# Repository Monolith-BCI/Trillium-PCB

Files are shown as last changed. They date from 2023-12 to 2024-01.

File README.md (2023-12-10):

## Monolith

We're a group of teens working on creating a BCI PCB to start running our own experiments on noise filtering, signal processing speed, and data collection. Our board takes in electrode data from 8 electrodes, and outputs the data over SPI so that we can process it with a neural network.

## Setup

KiCad plugins that we highly suggest installing:

* [`espressif/kicad-libraries`](https://github.com/espressif/kicad-libraries): KiCad libraries for Espressif chips and modules

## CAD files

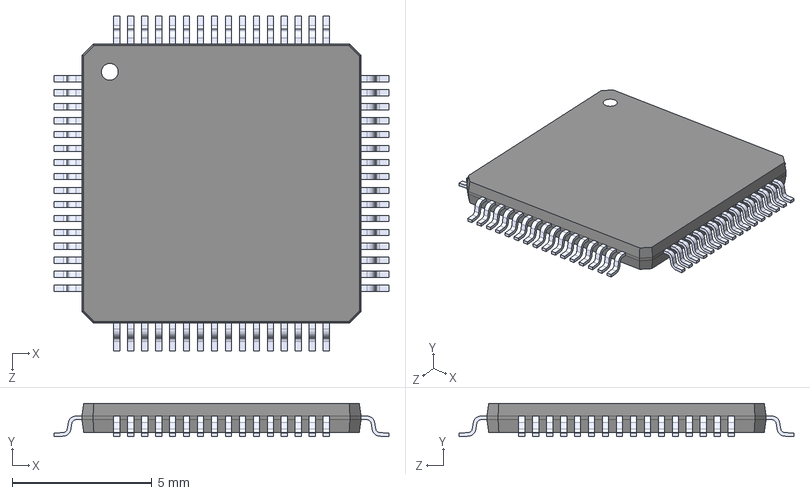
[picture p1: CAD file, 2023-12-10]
ADS1299IPAGR/ADS1299IPAGR.step
12.0 x 1.20 x 12.0 mm

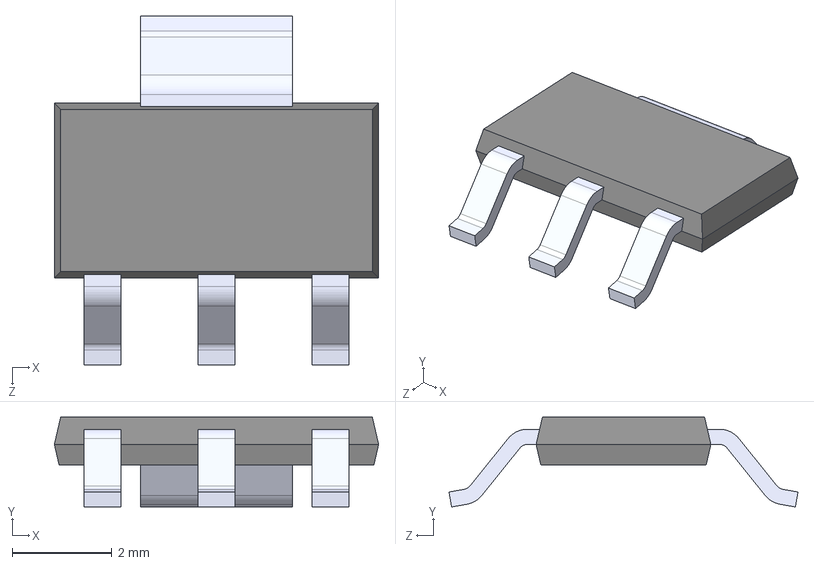
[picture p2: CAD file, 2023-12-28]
AMS1117-3.3/AMS1117-3.3.step
6.50 x 1.80 x 7.00 mm

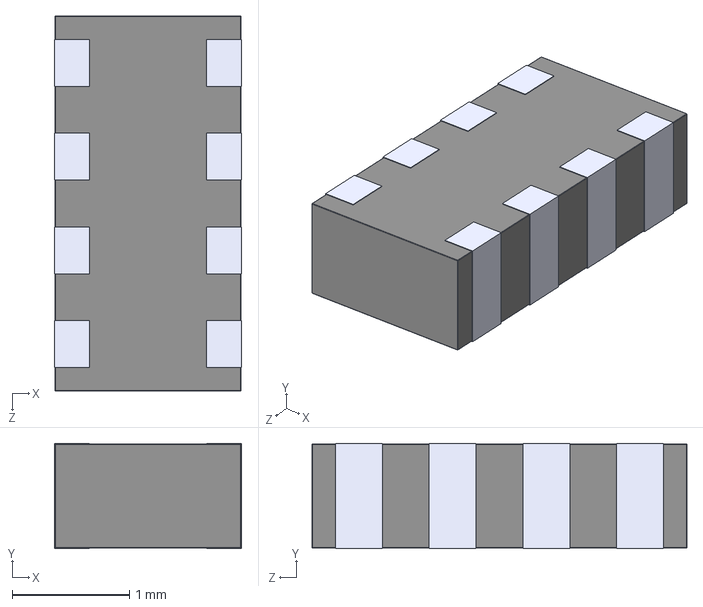
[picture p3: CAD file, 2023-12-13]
CA0612KRX7R9BB102/CA0612KRX7R9BB102.step
1.60 x 0.9 x 3.20 mm

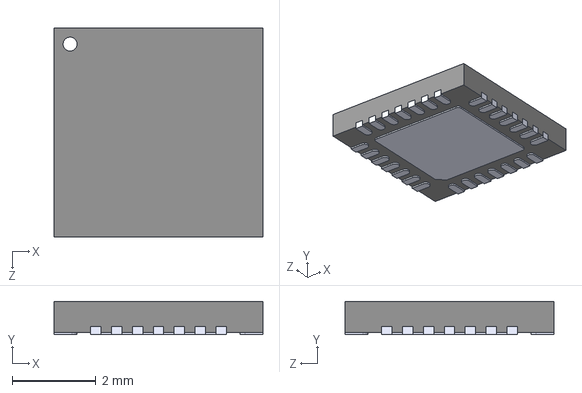
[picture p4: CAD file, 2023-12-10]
CP2102N_A02_GQFN28R/CP2102N-A02-GQFN28R.step
5.00 x 0.8 x 5.00 mm

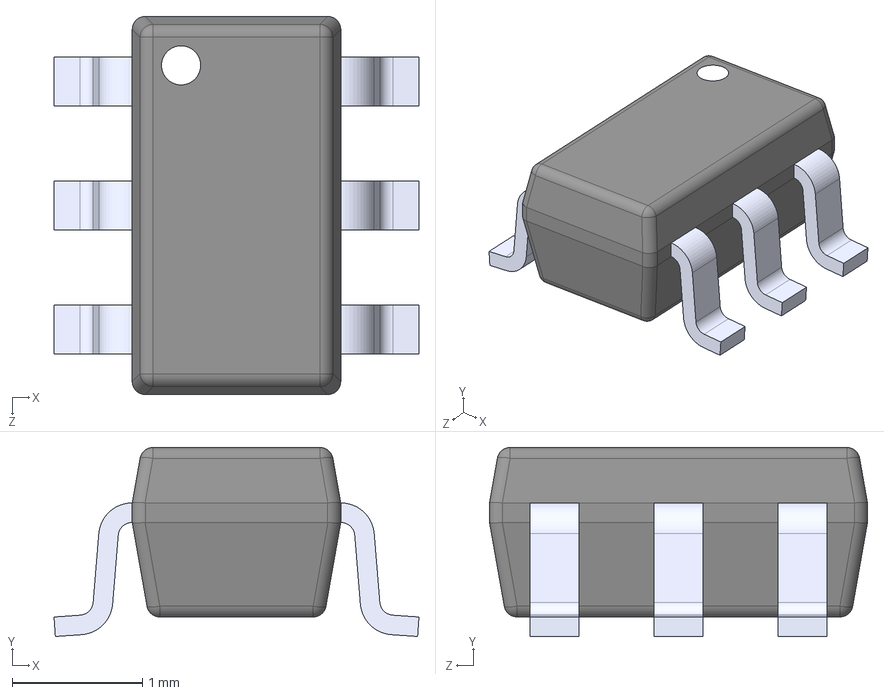
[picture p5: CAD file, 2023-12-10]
LM2664M6/LM2664M6.step
2.80 x 1.45 x 2.90 mm

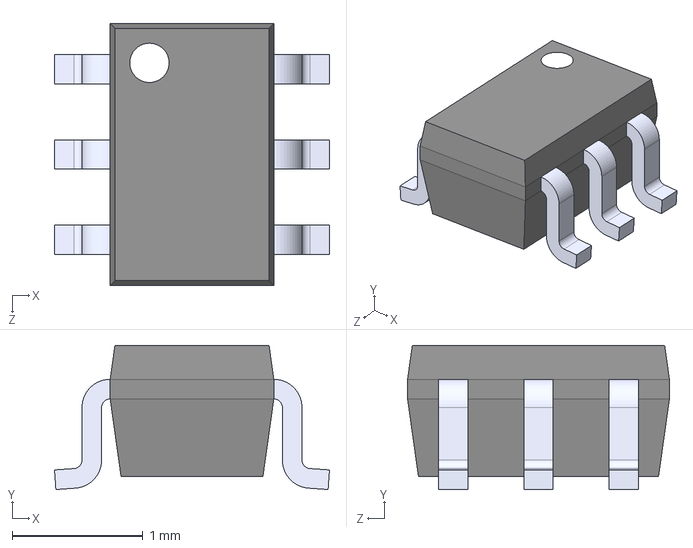
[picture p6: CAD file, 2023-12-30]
TPD4E1B06DCKR /TPD4E1B06DCKR.step
2.10 x 1.10 x 2.00 mm

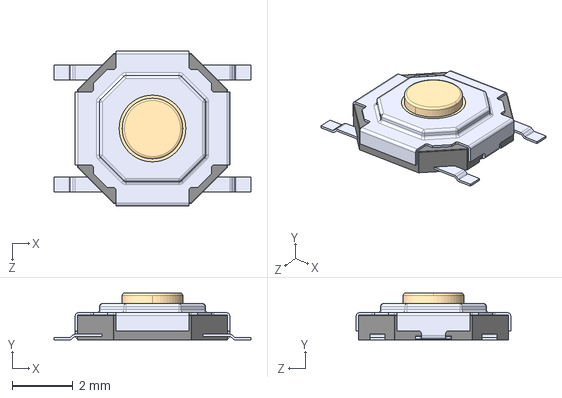
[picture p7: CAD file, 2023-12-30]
TS-1187A-B-A-B/TS-1187A-B-A-B.step
6.50 x 1.55 x 5.10 mm

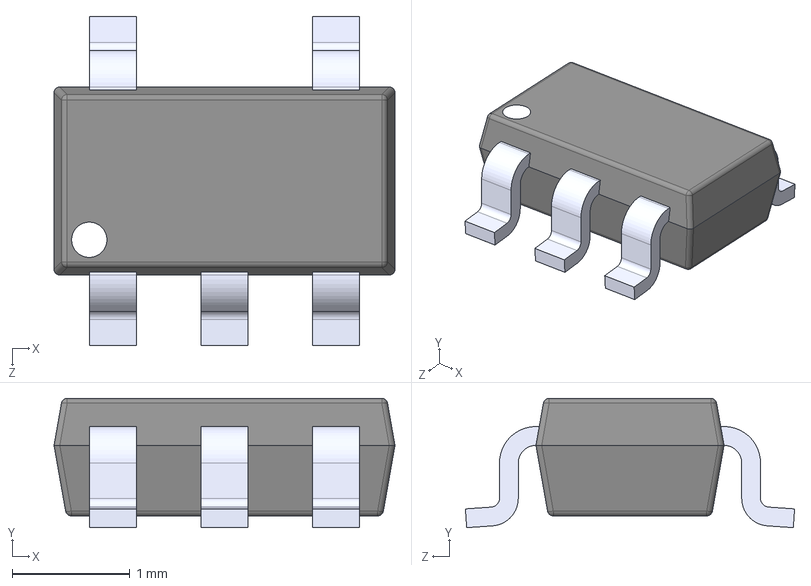
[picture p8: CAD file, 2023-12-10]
TLV70025QDDCRQ1/TLV70025QDDCRQ1.step
2.90 x 1.10 x 2.80 mm

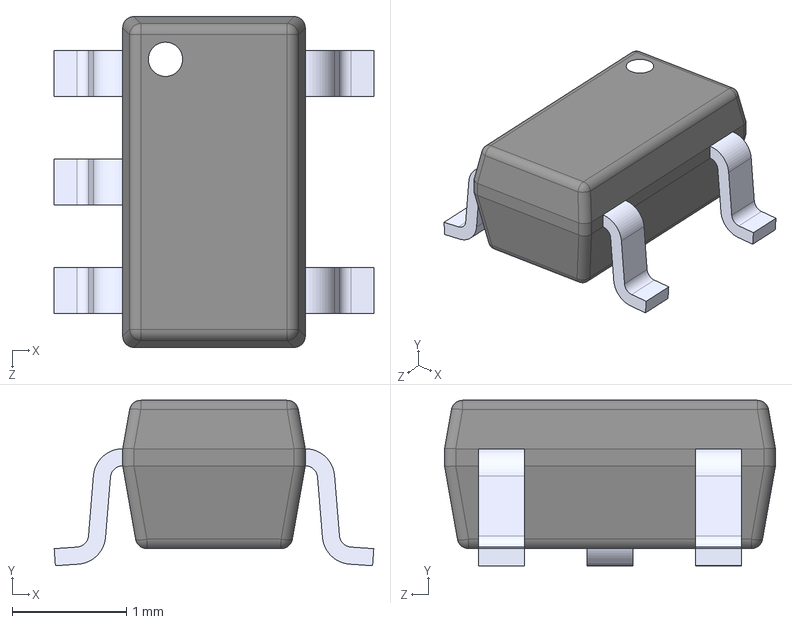
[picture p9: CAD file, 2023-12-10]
TPS72325DBVR/TPS72325DBVR.step
2.80 x 1.45 x 2.90 mm

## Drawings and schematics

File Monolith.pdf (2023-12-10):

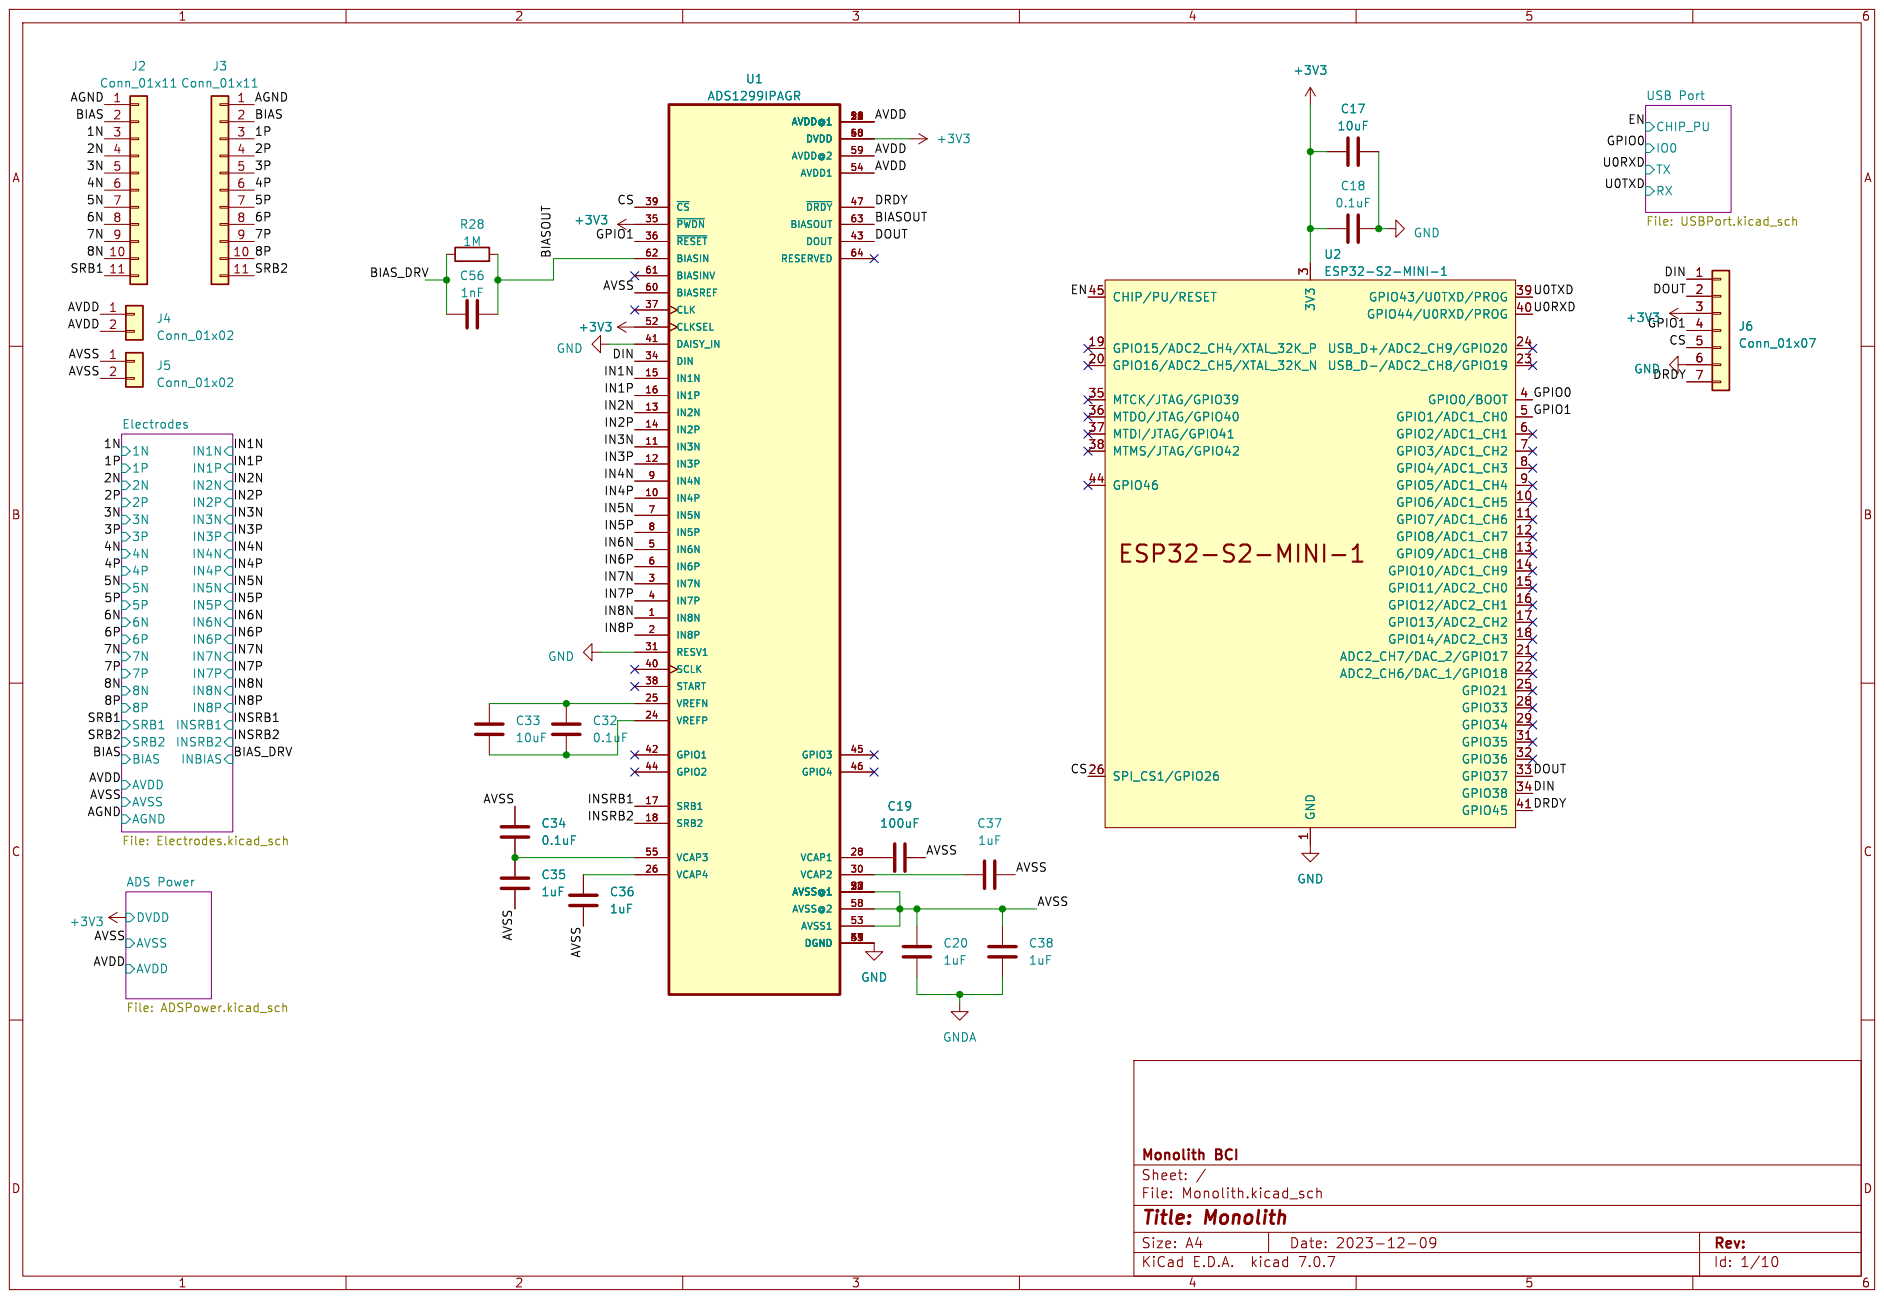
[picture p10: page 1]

3 GPIO35 31 GPIO36 32 GPIO37 33 GPIO38 34 MTCK/JTAG/GPIO39 35 MTDO/JTAG/GPIO40 36 MTDI/JTAG/GPIO41 37 MTMS/JTAG/GPIO42 38 GPIO43/U0TXD/PROG 39 GPIO0/BOOT 4 GPIO44/U0RXD/PROG 40 GPIO45 41 GPIO1/ADC1_CH0 5 GPIO2/ADC1_CH1 6 GPIO3/ADC1_CH2 7 GPIO4/ADC1_CH3 8 GPIO5/ADC1_CH4 9 U2ESP32-S2-MINI-1 R28

3 GPIO35 31 GPIO36 32 GPIO37 33 GPIO38 34 MTCK/JTAG/GPIO39 35 MTDO/JTAG/GPIO40 36 MTDI/JTAG/GPIO41 37 MTMS/JTAG/GPIO42 38 GPIO43/U0TXD/PROG 39 GPIO0/BOOT 4 GPIO44/U0RXD/PROG 40 GPIO45 41 GPIO1/ADC1_CH0 5 GPIO2/ADC1_CH1 6 GPIO3/ADC1_CH2 7 GPIO4/ADC1_CH3 8 GPIO5/ADC1_CH4 9 GND

ADS Power File: ADSPower.kicad_sch

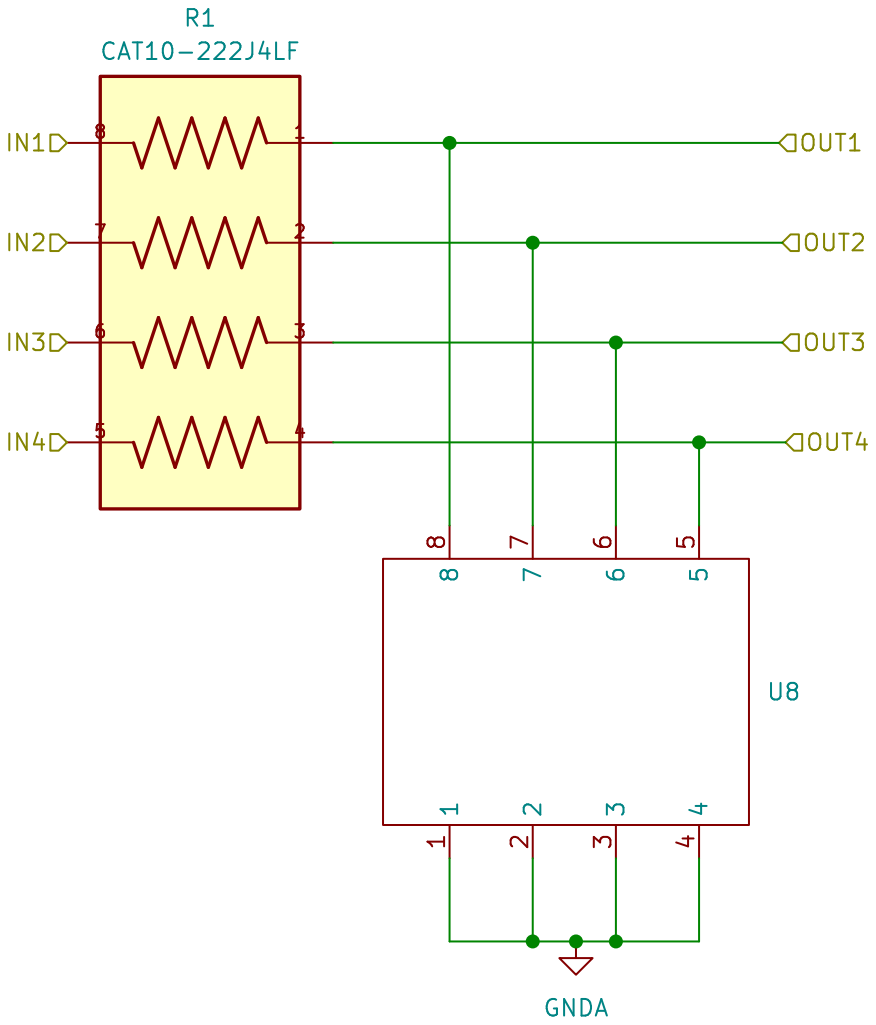
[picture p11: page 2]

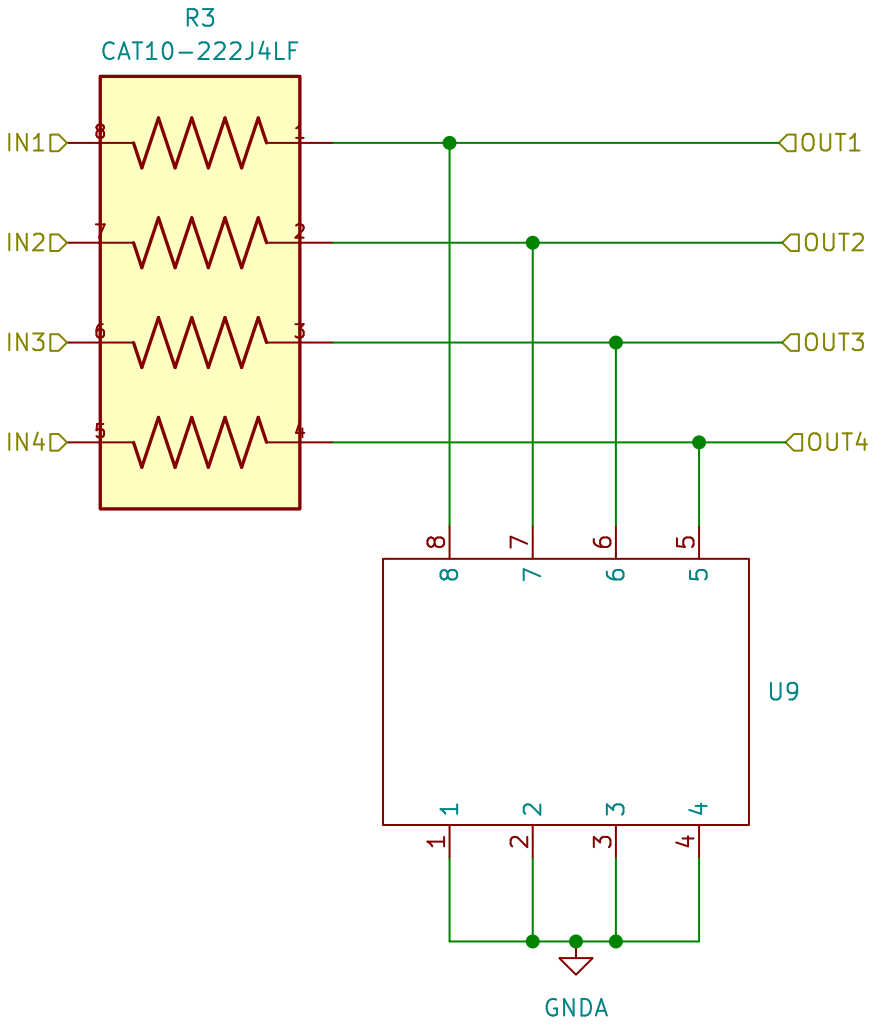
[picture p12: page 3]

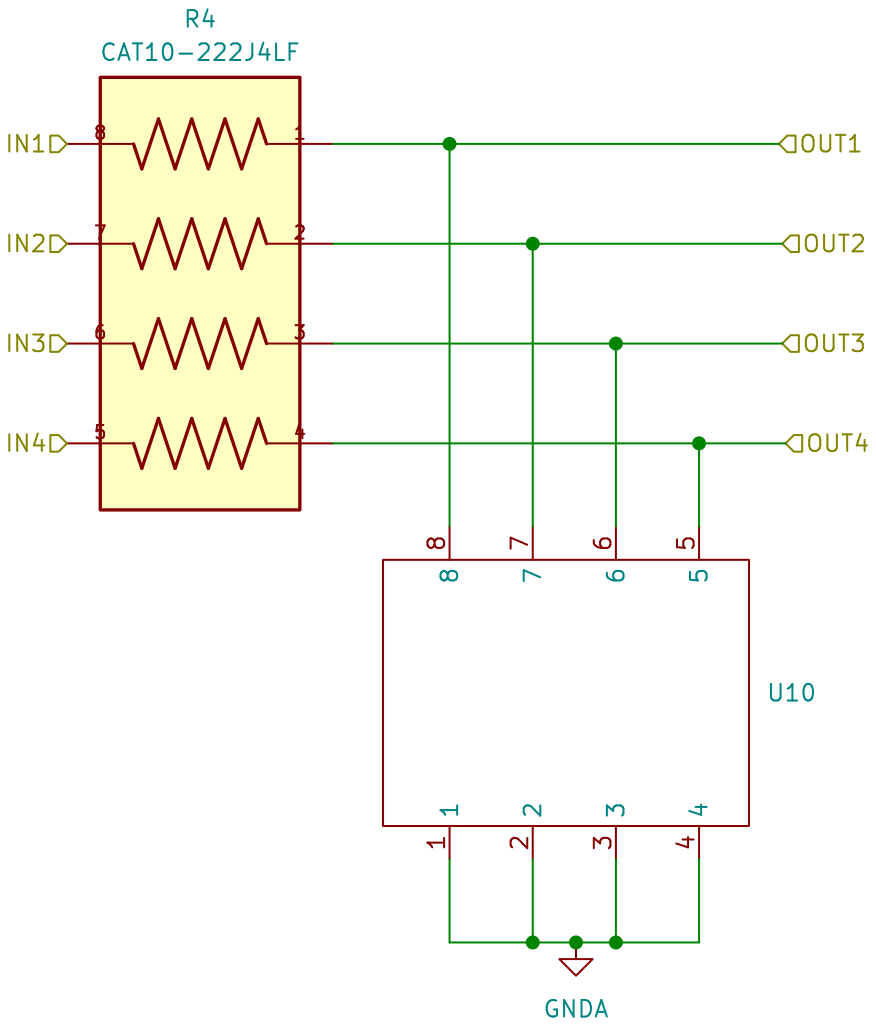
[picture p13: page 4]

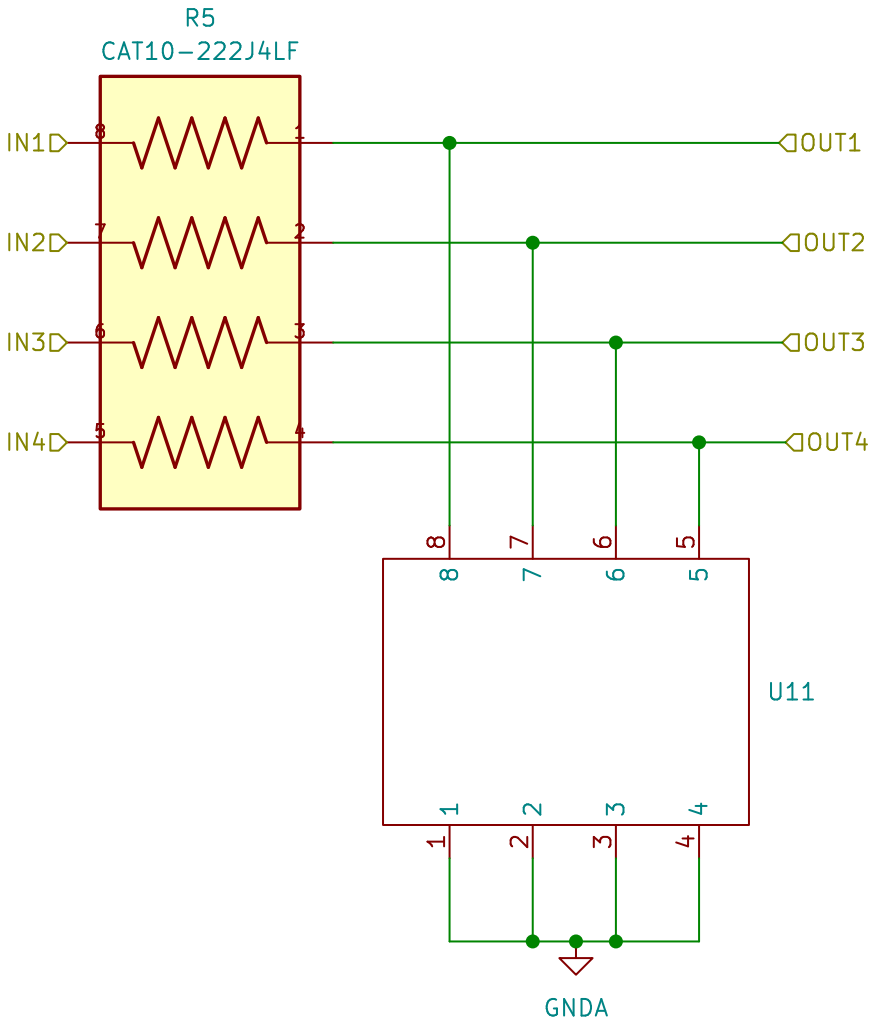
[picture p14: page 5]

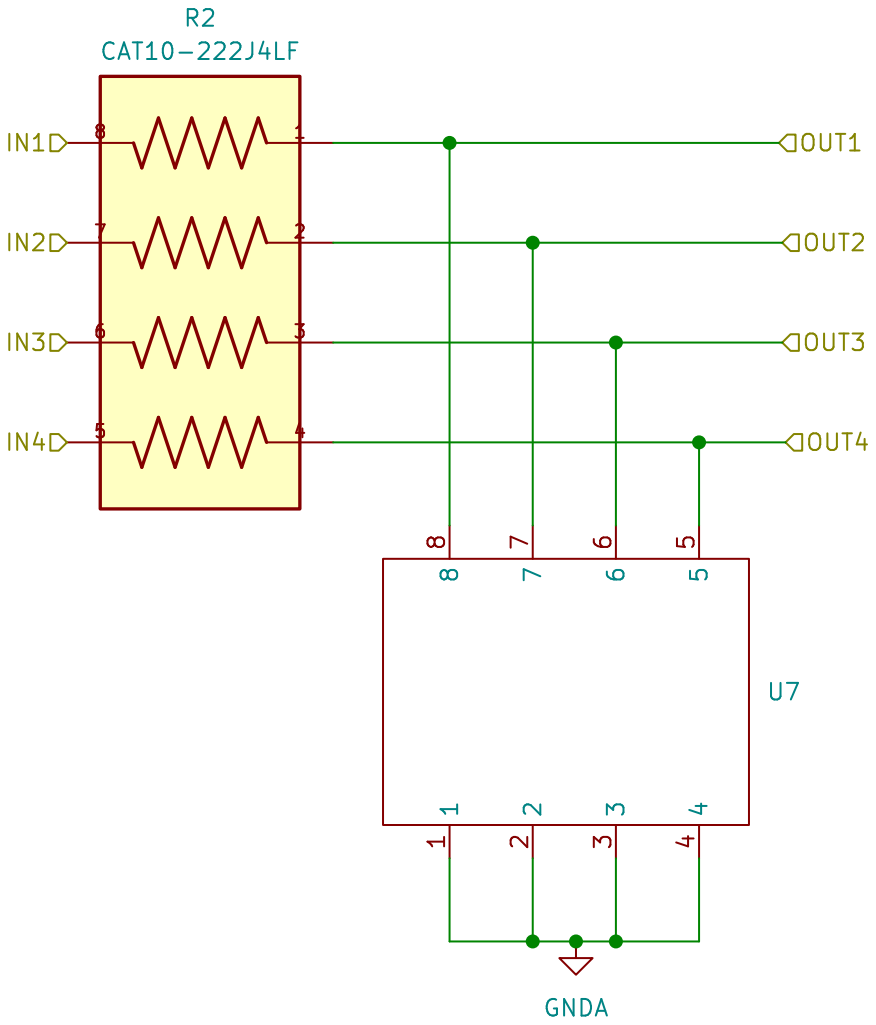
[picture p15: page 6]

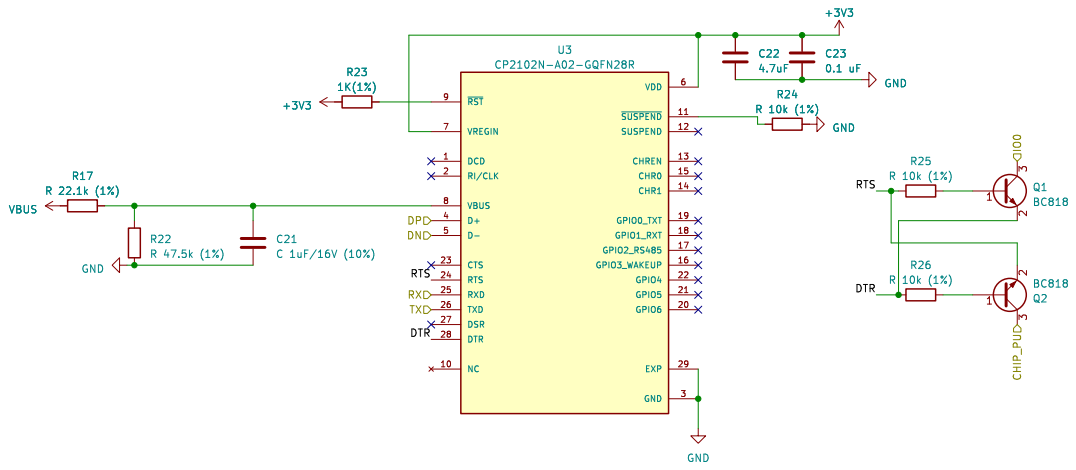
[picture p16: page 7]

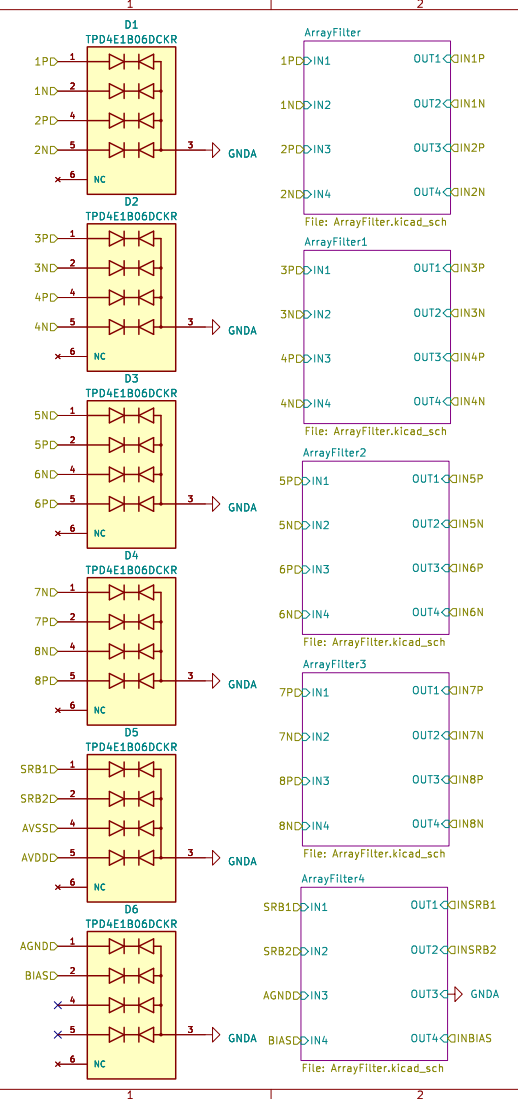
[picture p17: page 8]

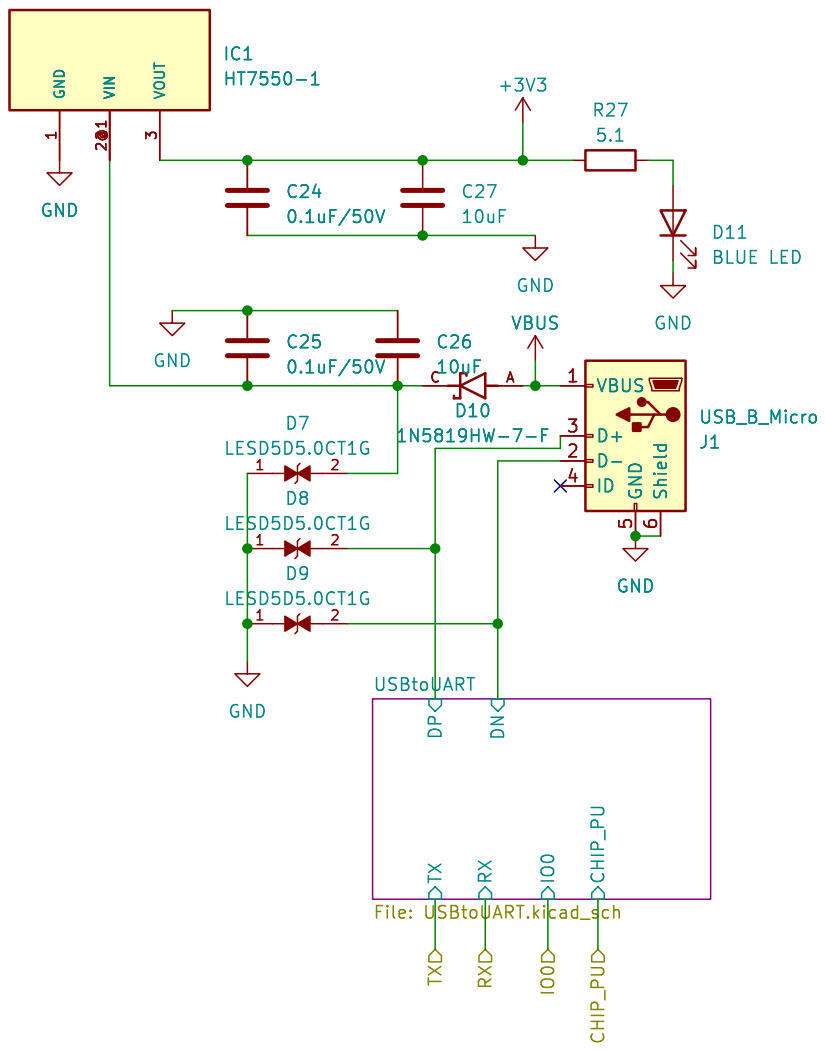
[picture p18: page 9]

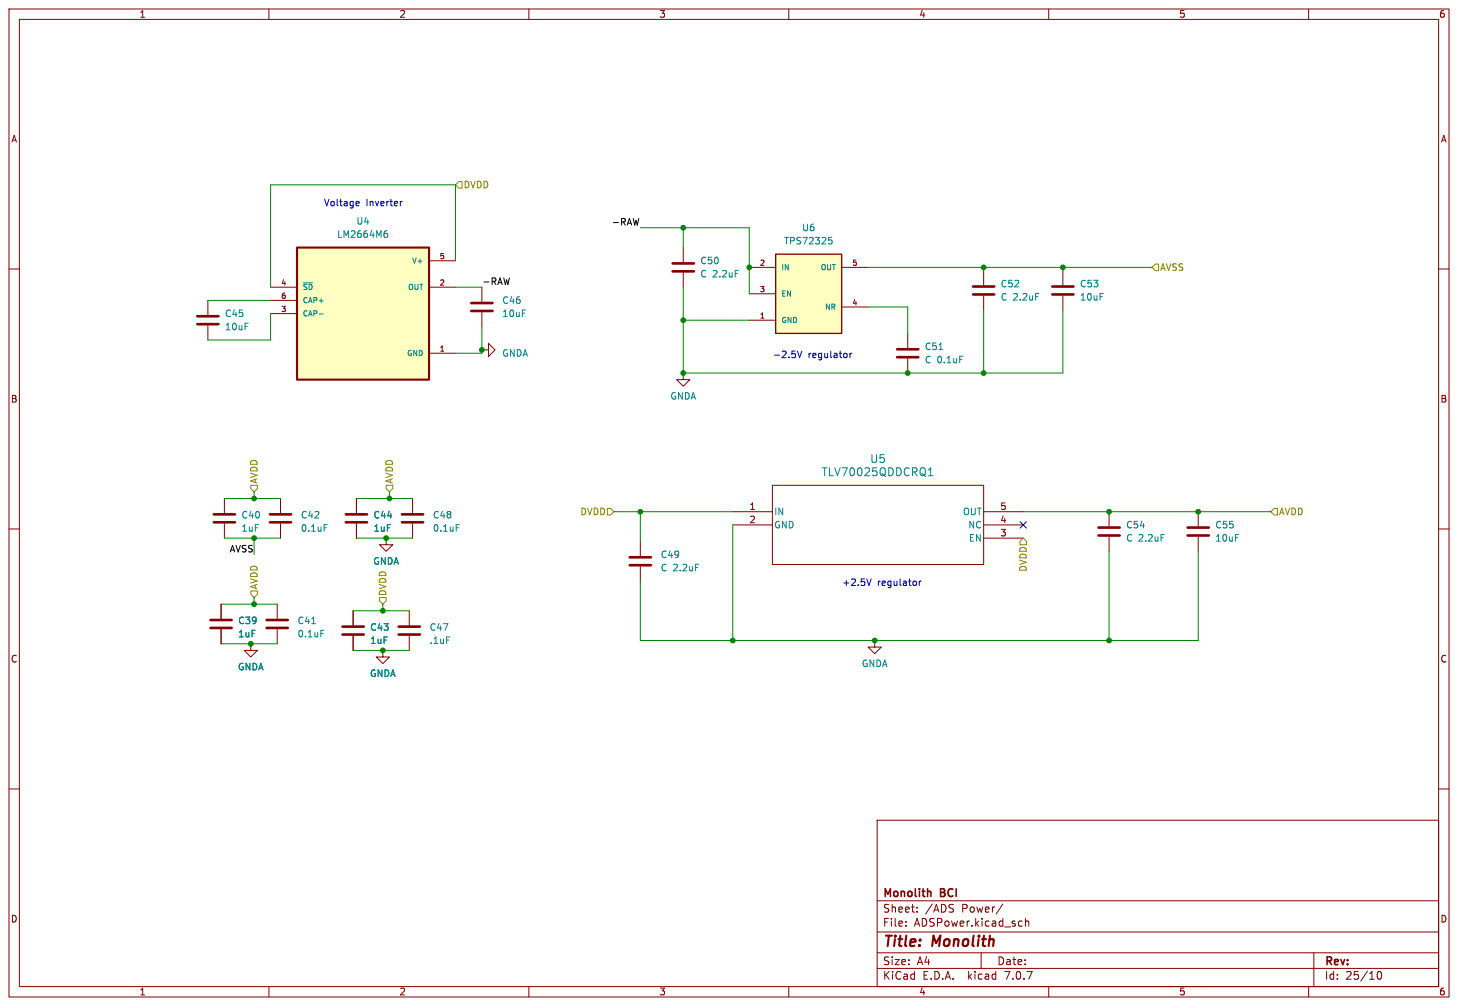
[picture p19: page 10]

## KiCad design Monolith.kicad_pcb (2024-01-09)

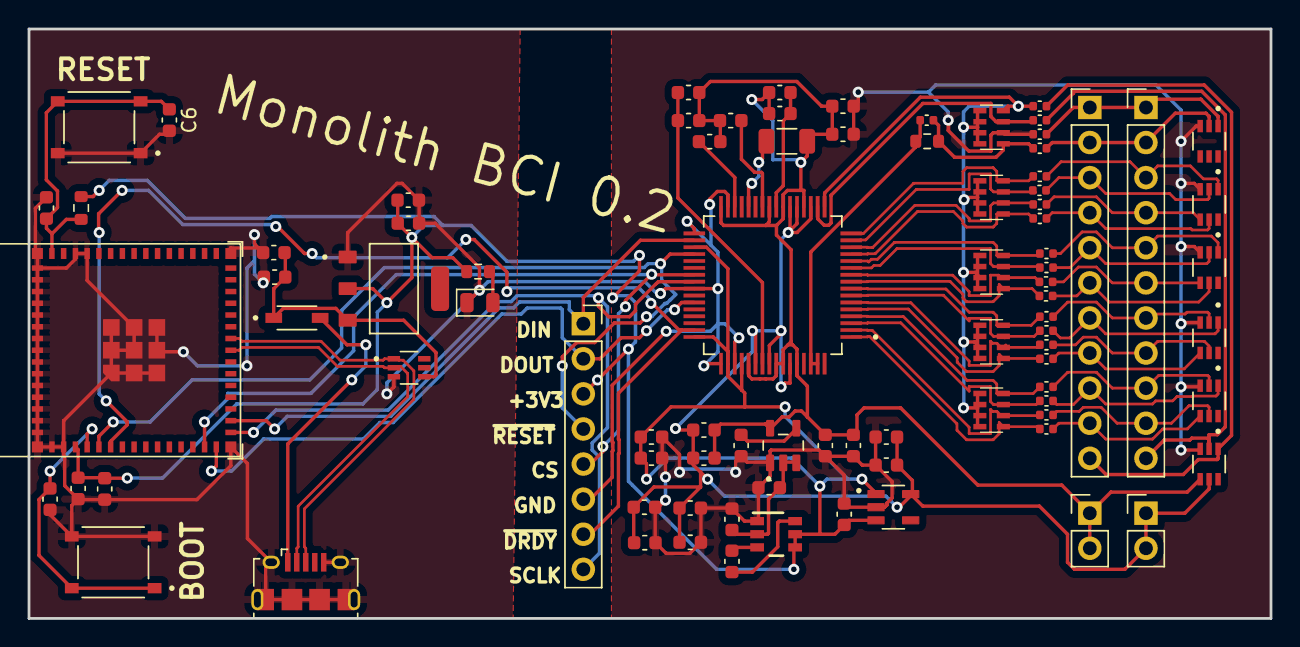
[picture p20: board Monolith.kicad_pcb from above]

Board: 2 copper layers, 89.9 x 42.7 mm, 87 parts (0 on the bottom side), 67 nets.

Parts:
C1, C26, C27, C33, C45, C46, C53, C55: 10uF; C_0603_1608Metric
C2, C4, C6, C20, C32, C34, C41, C42, C48: 0.1uF; C_0603_1608Metric
C3, C35, C36, C37, C38, C39, C40, C43, C44: 1uF; C_0603_1608Metric
C19: 100uF; C_1206_3216Metric
C24, C25: 0.1uF/50V; C_0603_1608Metric
C47: .1uF; C_0603_1608Metric
C49, C50, C52, C54: C 2.2uF; C_0603_1608Metric
C51: C 0.1uF; C_0603_1608Metric
C56: 1nF; C_0402_1005Metric
D1, D2, D3, D4, D5, D6, D12: TPD4E1B06DCKR; TVS_TPD4E1B06DCKR
D10: 1N5819HW-7-F; SOD3715X145N
D11: EMERALD LED; LED_0805_2012Metric
J1: USB_B_Micro; USB_Micro-B_Amphenol_10118194_Horizontal
J2, J3: Conn_01x11; PinHeader_1x11_P2.54mm_Vertical
J4, J5: Conn_01x02; PinHeader_1x02_P2.54mm_Vertical
J7: Conn_01x08; PinSocket_1x08_P2.54mm_Vertical
R1, R2, R3, R4, R5, R7, R8, R9, R10, R11, R12, R13, R14, R15, R16, R18, R19, R20, R21, R29: R 2.2k; C_0402_1005Metric
R6: 10k; R_0603_1608Metric
R27: 100; R_0603_1608Metric
R28: 1M; R_0603_1608Metric
S1, S2: TS-1187A-B-A-B; SW_TS-1187A-B-A-B
U1: ADS1299IPAGR; QFP50P1200X1200X120-64N
U2: AMS1117-3.3; SOT229P700X180-4N
U4: LM2664M6; SOT95P280X145-6N
U5: TLV70025QDDCRQ1; SOT95P280X110-5N
U6: TPS72325; SOT95P280X145-5N
U7, U8, U9, U10, U11: CAP_CA0612_3P2X1P6_YAG
U12: ESP32-S3-MINI-1

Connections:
+3V3: C1.2, C2.2, C24.1, C27.1, C43.1, C47.1, C49.1, J7.3, R6.1, R27.1, U1.35 (~PWDN), U1.48 (DVDD), U1.50 (DVDD), U1.52 (CLKSEL), U2.2 (VO), U4.4 (~SD), U4.5 (V+), U5.1 (IN), U5.3 (EN), U12.3 (3V3)
/1N: D1.2, J2.3, R11.1
/1P: D1.1, J3.3, R5.1
/2N: D1.5, J2.4, R29.1
/2P: D1.4, J3.4, R16.1
/3N: D2.2, J2.5, R7.1
/3P: D2.1, J3.5, R1.1
/4N: D2.5, J2.6, R18.1
/4P: D2.4, J3.6, R12.1
/5N: D3.1, J2.7, R8.1
/5P: D3.2, J3.7, R2.1
/6N: D3.4, J2.8, R19.1
/6P: D3.5, J3.8, R13.1
/7N: D4.1, J2.9, R9.1
/7P: D4.2, J3.9, R3.1
/8N: D4.4, J2.10, R20.1
/8P: D4.5, J3.10, R14.1
/ADS Power/-RAW: C46.1, C50.1, U4.2 (OUT), U6.2 (IN), U6.3 (EN)
/AGND: D6.1, J2.1, J3.1, R15.1
/AVDD: C39.1, C40.1, C41.1, C42.1, C44.1, C48.1, C54.1, C55.1, D5.5, J4.1, J4.2, U1.19 (AVDD@1), U1.21 (AVDD@1), U1.22 (AVDD@1), U1.54 (AVDD1), U1.56 (AVDD@1), U1.59 (AVDD@2), U5.5 (OUT)
/AVSS: C19.2, C20.1, C32.1, C33.1, C34.1, C35.2, C36.1, C37.1, C38.1, C40.2, C42.2, C52.1, C53.1, D5.4, J5.1, J5.2, U1.20 (AVSS@1), U1.23 (AVSS@1), U1.25 (VREFN), U1.32 (AVSS@1), U1.53 (AVSS1), U1.57 (AVSS@1), U1.58 (AVSS@2), U1.60 (BIASREF), U6.5 (OUT)
/BIAS: D6.2, J2.2, J3.2, R21.1
/BIASOUT: C56.1, R28.2, U1.62 (BIASIN), U1.63 (BIASOUT)
/BIAS_DRV: C56.2, R21.2, R28.1, U11.5
/CS: J7.5, U1.39 (~CS), U12.14 (GPIO10/TOUCH10/ADC1_CH9/FSPICS0/FSPIIO4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)
/DIN: J7.1, U1.34 (DIN), U12.17 (GPIO13/TOUCH13/ADC2_CH2/FSPIQ/FSPIIO7/S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)
/DN: D12.2, J1.2 (D-), U12.23 (GPIO19/U1RTS/ADC2_CH8/CLK_OUT2/USB_D-)
/DOUT: J7.2, U1.43 (DOUT), U12.15 (GPIO11/TOUCH11/ADC2_CH0/FSPID/FSPIIO5/S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)
/DP: D12.1, J1.3 (D+), U12.24 (GPIO20/U1CTS/ADC2_CH9/CLK_OUT1/USB_D+)
/DRDY: J7.7, U1.47 (~DRDY), U12.6 (GPIO2/TOUCH2/ADC1_CH1)
/GPIO1: J7.4, U1.36 (~RESET), U12.5 (GPIO1/TOUCH1/ADC1_CH0)
/IN1N: R11.2, U1.15 (IN1N), U7.7
/IN1P: R5.2, U1.16 (IN1P), U7.8
/IN2N: R29.2, U1.13 (IN2N), U7.5
/IN2P: R16.2, U1.14 (IN2P), U7.6
/IN3N: R7.2, U1.11 (IN3N), U8.7
/IN3P: R1.2, U1.12 (IN3P), U8.8
/IN4N: R18.2, U1.9 (IN4N), U8.5
/IN4P: R12.2, U1.10 (IN4P), U8.6
/IN5N: R8.2, U1.7 (IN5N), U9.7
/IN5P: R2.2, U1.8 (IN5P), U9.8
/IN6N: R19.2, U1.5 (IN6N), U9.5
/IN6P: R13.2, U1.6 (IN6P), U9.6
/IN7N: R9.2, U1.3 (IN7N), U10.7
/IN7P: R3.2, U1.4 (IN7P), U10.8
/IN8N: R20.2, U1.1 (IN8N), U10.5
/IN8P: R14.2, U1.2 (IN8P), U10.6
/INSRB1: R4.2, U1.17 (SRB1), U7.1, U7.2, U7.3, U7.4, U8.1, U8.2, U8.3, U8.4, U9.1, U9.2, U9.3, U9.4, U10.1, U10.2, U10.3, U10.4, U11.1, U11.2, U11.3, U11.4, U11.8
/INSRB2: R10.2, U1.18 (SRB2), U11.7
/SCLK: J7.8, U1.40 (SCLK), U12.16 (GPIO12/TOUCH12/ADC2_CH1/FSPICLK/FSPIIO6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)
/SRB1: D5.1, J2.11, R4.1
/SRB2: D5.2, J3.11, R10.1
GND: C1.1, C2.1, C3.2, C4.1, C6.2, C24.2, C25.1, C26.1, C27.2, D11.1 (K), D12.3, J1.5 (GND), J1.6 (Shield), J7.6, S1.A, S1.B, S2.C, S2.D, U1.31 (RESV1), U1.33 (DGND), U1.41 (DAISY_IN), U1.49 (DGND), U1.51 (DGND), U2.1 (GND), U12.1 (GND), U12.2 (GND), U12.42 (GND), U12.43 (GND), U12.46 (GND), U12.47 (GND), U12.48 (GND), U12.49 (GND), U12.50 (GND), U12.51 (GND), U12.52 (GND), U12.53 (GND), U12.54 (GND), U12.55 (GND), U12.56 (GND), U12.57 (GND), U12.58 (GND), U12.59 (GND), U12.60 (GND), U12.61 (GND), U12.62 (GND), U12.63 (GND), U12.64 (GND), U12.65 (GND)
GNDA: C20.2, C38.2, C39.2, C41.2, C43.2, C44.2, C46.2, C47.2, C48.2, C49.2, C50.2, C51.2, C52.2, C53.2, C54.2, C55.2, D1.3, D2.3, D3.3, D4.3, D5.3, D6.3, R15.2, U4.1 (GND), U5.2 (GND), U6.1 (GND), U11.6
unnamed: D11.2 (A), R27.2
unnamed: C19.1, U1.28 (VCAP1)
unnamed: C37.2, U1.30 (VCAP2)
unnamed: C34.2, C35.1, U1.55 (VCAP3)
unnamed: C36.2, U1.26 (VCAP4)
unnamed: C32.2, C33.2, U1.24 (VREFP)
unnamed: C25.2, C26.2, D10.C, D12.4, U2.3 (VI)
unnamed: C45.1, U4.6 (CAP+)
unnamed: C45.2, U4.3 (CAP-)
unnamed: C51.1, U6.4 (NR)
unnamed: C3.1, C6.1, R6.2, S1.C, S1.D, U12.45 (EN)
unnamed: C4.2, S2.A, S2.B, U12.4 (GPIO0/BOOT)
VBUS: D10.A, J1.1 (VBUS)

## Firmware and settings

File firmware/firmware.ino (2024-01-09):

#define PIN_SPI_SS 7
#define PIN_SPI_SCK 4
#define PIN_SPI_MOSI 6
#define PIN_SPI_MISO 5

#define WAKEUP 0x02
#define STANDBY 0x04
#define RESET 0x06
#define START 0x08
#define STOP 0x0A
#define RDATAC 0x10
#define SDATAC 0x11
#define RDATA 0x12


void setup()
{
  USBSerial.begin(9600);
}

void loop()
{
  USBSerial.println("hi");
}

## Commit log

2023-12-10 Clean up and commit
    [ADS1299IPAGR.step, ADSPower.kicad_sch, ArrayFilter.kicad_sch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]
2023-12-10 fix shorted pin
    [Monolith-B_Cu.gbr, Monolith-B_Mask.gbr, Monolith-B_Paste.gbr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]
2023-12-13 fix pick and place stuff
    [ADSPower.kicad_sch, ArrayFilter.kicad_sch, BOM.csv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]
2023-12-13 fix capacitor array footprint
    [ArrayFilter.kicad_sch, CA0612KRX7R9BB102.step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]
2023-12-13 fix usb
    [CPL.csv, Monolith-B_Cu.gbr, Monolith-B_Mask.gbr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]
2023-12-28 Switch out ESP32 for correct model
    [Monolith.kicad_sch]
2023-12-28 swap out esp
    [Monolith.kicad_sch]
2023-12-28 add pin for SCLK on header
    [Monolith.kicad_sch]
2023-12-28 Edit schematic
    [AMS1117-3.3.step, Monolith.kicad_sch, USBPort.kicad_sch]
2023-12-28 moar stuff
    [Monolith.kicad_pcb]
2023-12-28 fix led
    [USBPort.kicad_sch]
2023-12-28 Replace volt reg
    [Monolith.kicad_pcb, Monolith.kicad_sch]
2023-12-28 fix vrm
    [Monolith.kicad_pcb]
2023-12-29 add ground planes
    [Monolith.kicad_pcb]
2023-12-30 new fixes
    [ADSPower.kicad_sch, ArrayFilter.kicad_sch, Electrodes.kicad_sch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]
2023-12-31 ready to fab?
    [Monolith.kicad_pcb]
2023-12-31 fix pin headers
    [Monolith.kicad_pcb, Monolith.kicad_sch]
2024-01-01 change text
    [Monolith.kicad_pcb]
2024-01-01 remove ref designators
    [Monolith-B_Cu.gbr, Monolith-B_Mask.gbr, Monolith-B_Paste.gbr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]
2024-01-09 fix reset button
    [CPL.csv, Monolith-B_Cu.gbr, Monolith-B_Mask.gbr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]
